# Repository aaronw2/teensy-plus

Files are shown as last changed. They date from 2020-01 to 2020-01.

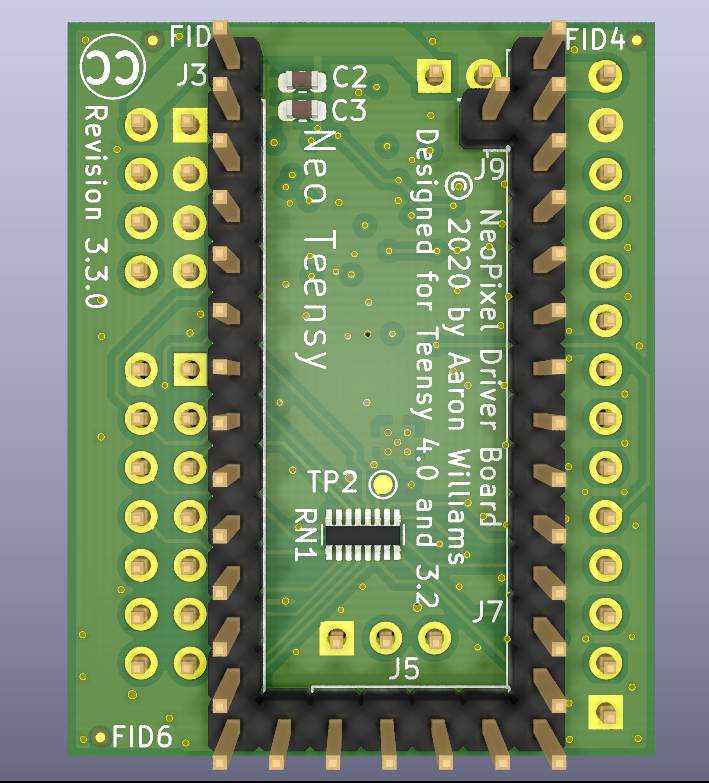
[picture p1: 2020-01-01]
Pictures/Back.png

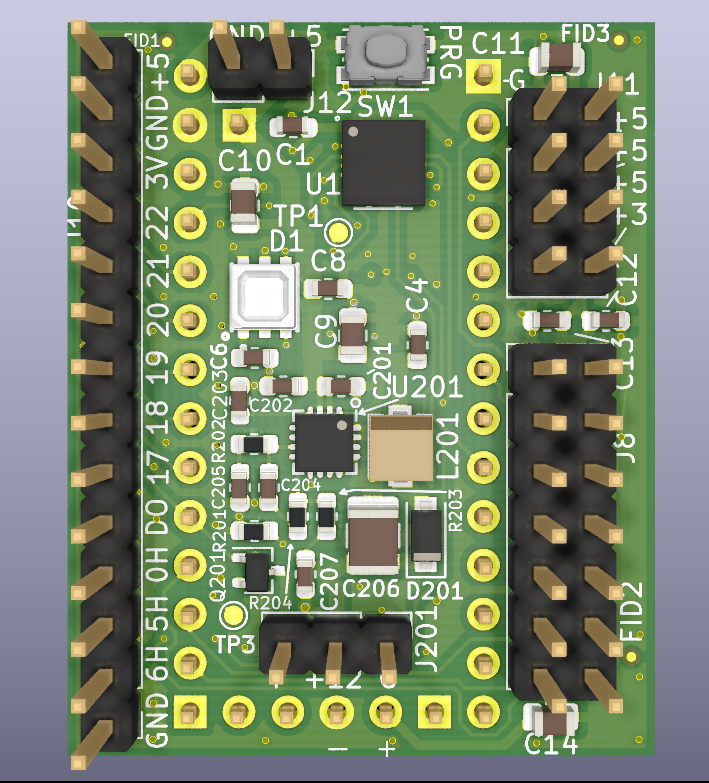
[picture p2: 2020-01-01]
Pictures/Front.png

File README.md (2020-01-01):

Teensy Plus
Revision 3.3

Copyright (C) 2019 by Aaron Williams

This board is designed to be mounted to a PJRC Teensy 4.0 and 3.2 board.
It brings out the I/Os of the Teensy and provides a 3V to 5V level shifter
and a WS2813mini NeoPixel in order to drive up to four channels of
NeoPixels.  The 5V channels should be compatible with the FastLED library
for the Teensy 4.0 (not 3.2).  In addition, this board provides a switchable
12V, 500ma output for driving a fan or other 12V accessories.  Note that
while the boost circuit is fairly efficient that it will draw around 2.75 times
as much current at 5V as the 12V output, so at 500ma it could potentially
draw around 1.4 amps.  If the 12V is not needed then it does not need to be
stuffed.

This board is designed to be mounted back-to-back with the Teensy 3.2 or
4.0 board. Note that the extra pins on the back will not be accessible
once this board is soldered in place.  It can be connected by soldering
board headers or using headers and sockets.

Not all of the pins are used and not all need to be hooked up.

On/OFF, Program and VBat are not hooked up.  Additionally J9 does not
need to be connected and can be used for an additional 5V pin.

IO0, IO1, IO2 and IO3 are passed to the level shifter and IO23 is
connected to the enable pin of the level shifter.  IO3 then goes to
the WS2813mini.

3.3V is obtained from the Teensy board which cannot supply a lot of
current.  Please do not exceed 100ma.

J8 brings provides 3.3V, ground and IO4 through IO15.  The pinout is:
J8:
1.  3.3V
2.  GND
3.  IO0
4.  IO1
5.  IO2
6.  IO3
7.  IO5
8.  IO4
9.  IO10
10. IO11
11. IO12
12. IO13
13. IO14
14. IO15

These pins are directly connected.

J10 brings out the other pins along with the 5V level shifted pins.  Note
that the level shifted pins pass through 22 ohm resistors to help reduce
noise and can optionally have capacitors connected in order to create a
low-pass filter.

Pins 2-5 pass through the level shifter, however, pin1 is an output only
that is connected to the output of the WS2813mini.

J10:
1.  GND
2.  IO8  (5V)
3.  IO9  (5V)
4.  IO6  (5V)
5.  DO   (5V, output of WS2813-mini)
6.  IO17 (3.3v, bi-directional)
7.  IO18 (3.3v, bi-directional)
8.  IO19 (3.3v, bi-directional)
9.  IO20 (3.3v, bi-directional)
10. IO21 (3.3v, bi-directional)
11. IO22 (3.3v, bi-directional)
12. 3.3V (output)
13. 5V (output)
14. Ground

J11 is used for power input and output.
1. Ground
2. +5V
3. Ground
4. +5V
5. Ground
6. +5V
7. Ground
8. +3.3V

J12 is also used for power.
1. +5V
2. Ground

J201 provides 12V at up to 500ma.
1. GND
2. +12
3. Switched ground (IO17 high enables ground), used for turning fans on/off

Power: This board can either provide 5V or receive 5V from the Teensy.
Note that it expects a battery to not be hooked up and for the input
to already be regulated to 5V.

3.3V comes from the Teensy.  Note that the Teensy can only supply a limited
amount of current at 3.3V.

Level shifter:
A SN74AHCT125N buffer is used to provide 5V I/O.  IO23 is connected
directly to the enable pin and must be pulled low in order to enable the
5V I/O. Pulling IO23 high will tri-state the bi-directional level shifter.

NOTE: Only use the Texas Instraments SN74AHCT125N!  Other manufacturers
do not support 3V input.

BOM:
C1, C2, C4, C8, C13     CAP CER 0.1UF 16V X7R 0603
C3, C65, C12            CAP CER 1UF 25V X7R 0603
C9, C10, C11, C14       CAP CER 10UF 10V X7R 0805
D1                      WS2813-MINI neopixel, available from LCSC
RN1                     47K Panasonic EXB-Q16P473J Resistor Netowrk 15
U1                      SN74AHCT125N (TI only!!!)

12V BOM:
C201                    CAP CER 22UF 16V X5R 0603
C202                    CAP CER 0.1UF 16V X7R 0603
C203                    CAP CER 0.022UF 50V X7R 0603
C204                    CAP CER 820PF 50V X7R 0603
C205                    CAP CER 0.047UF 50V X7R 0603
C206                    CAP CER 47UF 16V X5R 1210
D201                    SS24FL DIODE SCHOTTKY 40V 2A SOD123F
Q201                    BSS214NW MOSFET N-CH 20V 1.5A SOT323
R201                    RES SMD 18.7K OHM 1% 1/10W 0603
R202                    RES SMD 1.62K OHM 1% 1/10W 0603
R203                    RES SMD 86.6K OHM 1% 1/10W 0603
R204                    RES SMD 10K OHM 1% 1/10W 0603
R205                    RES SMD 100K OHM 1% 1/10W 0603
                        (can use 86.6K or higher resistor)

All components except the WS2813-mini can be sourced from Digikey.
Why did I use a WS2813-mini? I bought a reel of 1500 of them and the
footprint I have is a bit smaller than the WS2812-mini.

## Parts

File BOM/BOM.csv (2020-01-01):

Refs | Value | Footprint | Quantity | DESC | MFR | MPN | SPR | SPN | SPURL
L201 | 3.3uH | Aaron:L_Vishay_IHLP-1212 | 1 | FIXED IND 3.3UH 2.7A 61 MOHM SMD | Vishay Dale | IHLP1212BZER3R3M11 | Digikey | 541-2567-1-ND | https://www.digikey.com/product-detail/en/IHLP1212BZER3R3M11/541-2567-1-ND
U201 | TPS55340-Q1 | Aaron:QFN-16-1EP_3x3mm_P0.5mm_EP2.7x2.7mm_ThermalVias | 1 | IC REG BOOST ADJ 5.25A 16WQFN | TI | TPS55340RTER | Digikey | 296-37677-1-ND | https://www.digikey.com/products/en?keywords=296-37677-1-ND
SW1 | SW_SPST_KMR2 | Aaron:SW_SPST_KMR2 | 1 | SWITCH TACTILE SPST-NO 0.05A 32V | C&K | KMR211NG LFS | Digikey | CKN10243CT-ND | https://www.digikey.com/product-detail/en/c-k/KMR211NG-LFS/CKN10243CT-ND/2176494
C2;C13;C8;C4;C1;C202 | 0.1uF | Capacitor_SMD:C_0603_1608Metric | 6 | CAP CER 0.1UF 16V X7R 0603 | Samsung | CL10B104KO8WPNC | Digikey | 1276-6582-1-ND | https://www.digikey.com/products/en?keywords=1276-6582-1-ND
C3;C12;C6;C207 | 1uF | Capacitor_SMD:C_0603_1608Metric | 4 | CAP CER 1UF 25V X7R 0603 | Samsung | CL10B105KA8NNNC | Digikey | 1276-1184-1-ND | https://www.digikey.com/products/en?keywords=1276-1184-1-ND
C203 | 22nF | Capacitor_SMD:C_0603_1608Metric | 1 | CAP CER 0.022UF 50V X7R 0603 | Samsung | CL10B223KB8WPNC | Digikey | 1276-6534-1-ND | https://www.digikey.com/products/en?keywords=1276-6534-1-ND
C201 | 22uF | Capacitor_SMD:C_0603_1608Metric | 1 | CAP CER 22UF 16V X5R 0603 | Samsung Electro-Mechanics | CL10A226MO7JZNC | Digikey | 1276-7076-1-ND | https://www.digikey.com/products/en?keywords=1276-7076-1-ND
C205 | 47nF | Capacitor_SMD:C_0603_1608Metric | 1 | CAP CER 0.047UF 50V X7R 0603 | Samsung Electro-Mechanics | CL10B473KB8WPNC | Digikey | 1276-6540-1-ND | https://www.digikey.com/product-detail/en/samsung-electro-mechanics/CL10B473KB8WPNC/1276-6540-1-ND/
C204 | 820pF | Capacitor_SMD:C_0603_1608Metric | 1 | CAP CER 820PF 50V X7R 0603 | Kemet | C0603C821J5RACTU | Digikey | 399-9127-1-ND | https://www.digikey.com/products/en?keywords=399-9127-1-ND
C14;C9;C11;C10 | 10uF | Capacitor_SMD:C_0805_2012Metric | 4 | CAP CER 10UF 10V X7R 0805 | Murata Electronics | GRM21BR71A106KA73K | Digikey | 490-14381-1-ND | https://www.digikey.com/products/en?keywords=490-14381-1-ND
C206 | 47uF | Capacitor_SMD:C_1210_3225Metric | 1 | CAP CER 47UF 16V X5R 1210 | Samsung | CL32A476KOJNNNE | Digikey | 1276-3376-1-ND | https://www.digikey.com/product-detail/en/samsung-electro-mechanics/CL32A476KOJNNNE/1276-3376-1-ND/3891462
J9 | Conn_01x01_Male | Connector_PinHeader_2.54mm:PinHeader_1x01_P2.54mm_Vertical | 1 | - | - | - | - | - | -
J12 | Conn_01x02 | Connector_PinHeader_2.54mm:PinHeader_1x02_P2.54mm_Vertical | 1 | - | - | - | - | - | -
J201 | Conn_01x03 | Connector_PinHeader_2.54mm:PinHeader_1x03_P2.54mm_Vertical | 1 | - | - | - | - | - | -
J5 | Conn_01x05_Male | Connector_PinHeader_2.54mm:PinHeader_1x05_P2.54mm_Vertical | 1 | - | - | - | - | - | -
J10 | Conn_01x14 | Connector_PinHeader_2.54mm:PinHeader_1x14_P2.54mm_Vertical | 1 | - | - | - | - | - | -
J3;J7 | Conn_01x14_Male | Connector_PinHeader_2.54mm:PinHeader_1x14_P2.54mm_Vertical | 2 | - | - | - | - | - | -
J11 | Conn_02x04_Odd_Even | Connector_PinHeader_2.54mm:PinHeader_2x04_P2.54mm_Vertical | 1 | - | - | - | - | - | -
J8 | Conn_02x07_Odd_Even | Connector_PinHeader_2.54mm:PinHeader_2x07_P2.54mm_Vertical | 1 | - | - | - | - | - | -
D201 | SS24FL | Diode_SMD:D_SOD-123F | 1 | DIODE SCHOTTKY 40V 2A SOD123F | ON | SS24FL | Digikey | SS24FLCT-ND | https://www.digikey.com/products/en?keywords=SS24FLCT-ND
D1 | WS2813-MINI | LED_WS2813-mini:LED_WS2813-MINI-2 | 1 | RGB 620~625nm Red, 515~525nm Green, 465~475nm Blue SMD-6 Light Emitting Diodes (LED) RoHS | Worldsemi | WS2813-Mini(WS2813-3535) | LCSC | C189639 | https://lcsc.com/product-detail/Others_WS2813-Mini-WS2813-3535_C189639.html
U1 | SN74AHCT125N | Package_DFN_QFN:Texas_S-PVQFN-N14 | 1 | IC BUF NON-INVERT 5.5V 14VQFN | Texas Instruments | SN74AHCT125RGYR | Digikey | 296-13910-1-ND | https://www.digikey.com/products/en?keywords=296-13910-1-ND
Q201 | BSS214NW | Package_TO_SOT_SMD:SOT-323_SC-70 | 1 | MOSFET N-CH 20V 1.5A SOT323 | Infineon | BSS214NWH6327XTSA1 | Digikey | BSS214NWH6327XTSA1CT-ND | https://www.digikey.com/products/en?keywords=BSS214NWH6327XTSA1CT-ND
R202 | 1.62k | Resistor_SMD:R_0603_1608Metric | 1 | RES SMD 1.62K OHM 1% 1/10W 0603 | Yageo | RC0603FR-071K62L | Digikey | 311-1.62KHRCT-ND | https://www.digikey.com/product-detail/en/yageo/RC0603FR-071K62L/311-1.62KHRCT-ND/729816
R204 | 10k | Resistor_SMD:R_0603_1608Metric | 1 | RES SMD 10K OHM 1% 1/10W 0603 | Vishay Dale | CRCW060310K0FKEC | Digikey | 541-2979-1-ND | https://www.digikey.com/products/en?keywords=541-2979-1-ND
R201 | 18.7K | Resistor_SMD:R_0603_1608Metric | 1 | RES SMD 18.7K OHM 1% 1/10W 0603 | Yageo | RC0603FR-0718K7L | Digikey | 311-18.7KHRCT-ND | https://www.digikey.com/product-detail/en/yageo/RC0603FR-0718K7L/311-18.7KHRCT-ND/729940
R203 | 86.6k | Resistor_SMD:R_0603_1608Metric | 1 | RES SMD 86.6K OHM 1% 1/10W 0603 | Vishay Dale | CRCW060386K6FKEA | Digikey | 541-86.6KHCT-ND | https://www.digikey.com/products/en?keywords=541-86.6KHCT-ND
RN1 | 47K | Resistor_SMD:R_Array_Convex_8x0602 | 1 | RES ARRAY 15 RES 47K OHM 1506 | Panasonic | EXB-Q16P473J | Digikey | U6473CT-ND | https://www.digikey.com/product-detail/en/panasonic-electronic-components/EXB-Q16P473J/U6473CT-ND/672854

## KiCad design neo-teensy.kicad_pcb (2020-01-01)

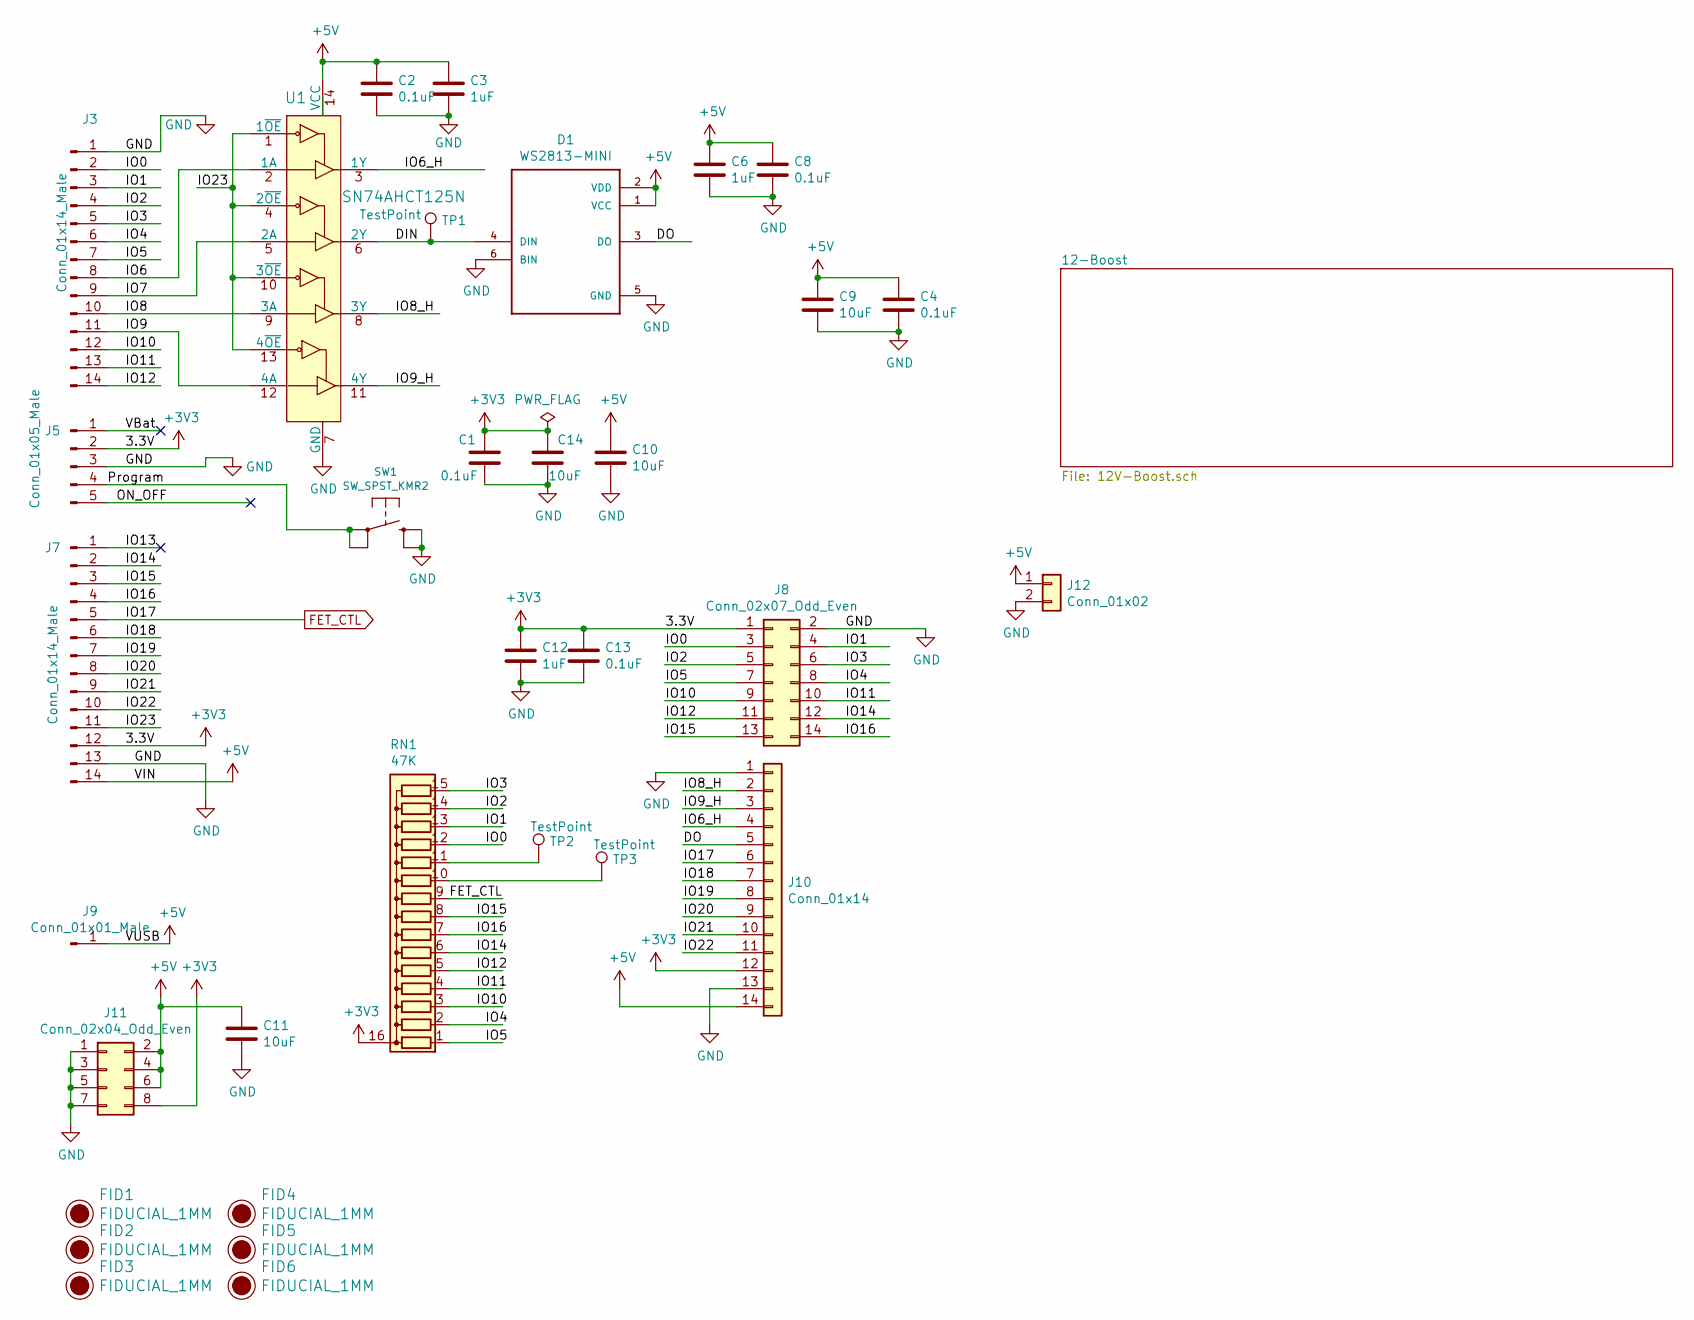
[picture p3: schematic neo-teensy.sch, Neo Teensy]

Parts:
C1, C2, C4, C8, C13: 0.1uF; C_0603_1608Metric; MPN CL10B104KO8WPNC
C3, C6, C12: 1uF; C_0603_1608Metric; MPN CL10B105KA8NNNC
C9, C10, C11, C14: 10uF; C_0805_2012Metric; MPN GRM21BR71A106KA73K
D1: WS2813-MINI; LED_WS2813-MINI-2; MPN WS2813-Mini(WS2813-3535)
FID1, FID2, FID3, FID4, FID5, FID6: FIDUCIAL_1MM; Fiducial_0.5mm_Mask1mm
J3, J7: Conn_01x14_Male; PinHeader_1x14_P2.54mm_Vertical
J5: Conn_01x05_Male; PinHeader_1x05_P2.54mm_Vertical
J8: Conn_02x07_Odd_Even; PinHeader_2x07_P2.54mm_Vertical
J9: Conn_01x01_Male; PinHeader_1x01_P2.54mm_Vertical
J10: Conn_01x14; PinHeader_1x14_P2.54mm_Vertical
J11: Conn_02x04_Odd_Even; PinHeader_2x04_P2.54mm_Vertical
J12: Conn_01x02; PinHeader_1x02_P2.54mm_Vertical
RN1: 47K; R_Array_Convex_8x0602; MPN EXB-Q16P473J
SW1: SW_SPST_KMR2; MPN KMR211NG LFS
TP1, TP2, TP3: TestPoint; TestPoint_Pad_D1.0mm
U1: SN74AHCT125N; Texas_S-PVQFN-N14; MPN SN74AHCT125RGYR; Digi-Key_PN 296-4655-5-ND

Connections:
+3V3: C1.1, C12.1, C13.1, C14.1, J5.2, J7.12, J8.1, J10.12, J11.8, RN1.16 (common)
+5V: C2.1, C3.1, C4.1, C6.1, C8.1, C9.1, C10.1, C11.1, D1.1 (VCC), D1.2 (VDD), J7.14, J9.1, J10.14, J11.2, J11.4, J11.6, J12.1, U1.14 (VCC); also elsewhere on the board
/DIN: D1.4 (DIN), TP1.1, U1.6 (2Y)
/DO: D1.3 (DO), J10.5
/IO0: J3.2, J8.3, RN1.12 (R11)
/IO1: J3.3, J8.4, RN1.13 (R12)
/IO2: J3.4, J8.5, RN1.14 (R13)
/IO3: J3.5, J8.6, RN1.15
/IO4: J3.6, J8.8, RN1.2 (R1)
/IO5: J3.7, J8.7, RN1.1
/IO6: J3.8, U1.2 (1A)
/IO6_H: J10.4, U1.3 (1Y)
/IO7: J3.9, U1.5 (2A)
/IO8: J3.10, U1.9 (3A)
/IO8_H: J10.2, U1.8 (3Y)
/IO9: J3.11, U1.12 (4A)
/IO9_H: J10.3, U1.11 (4Y)
/IO10: J3.12, J8.9, RN1.3 (R2)
/IO11: J3.13, J8.10, RN1.4 (R3)
/IO12: J3.14, J8.11, RN1.5 (R4)
/IO13: J7.1
/IO14: J7.2, J8.12, RN1.6 (R5)
/IO15: J7.3, J8.13, RN1.8 (R7)
/IO16: J7.4, J8.14, RN1.7 (R6)
/IO18: J7.6, J10.7
/IO19: J7.7, J10.8
/IO20: J7.8, J10.9
/IO21: J7.9, J10.10
/IO22: J7.10, J10.11
/IO23: J7.11, U1.1 (1~OE), U1.4 (2~OE), U1.10 (3~OE), U1.13 (4~OE)
/ON_OFF: J5.5
/Program: J5.4, SW1.1
/VBat: J5.1
FET_CTL: J7.5, J10.6, RN1.9 (R8); also elsewhere on the board
GND: C1.2, C2.2, C3.2, C4.2, C6.2, C8.2, C9.2, C10.2, C11.2, C12.2, C13.2, C14.2, D1.5 (GND), D1.6 (BIN), J3.1, J5.3, J7.13, J8.2, J10.1, J10.13, J11.1, J11.3, J11.5, J11.7, J12.2, SW1.2 (S), U1.7 (GND); also elsewhere on the board
unnamed: RN1.10 (R9), TP3.1
unnamed: RN1.11 (R10), TP2.1

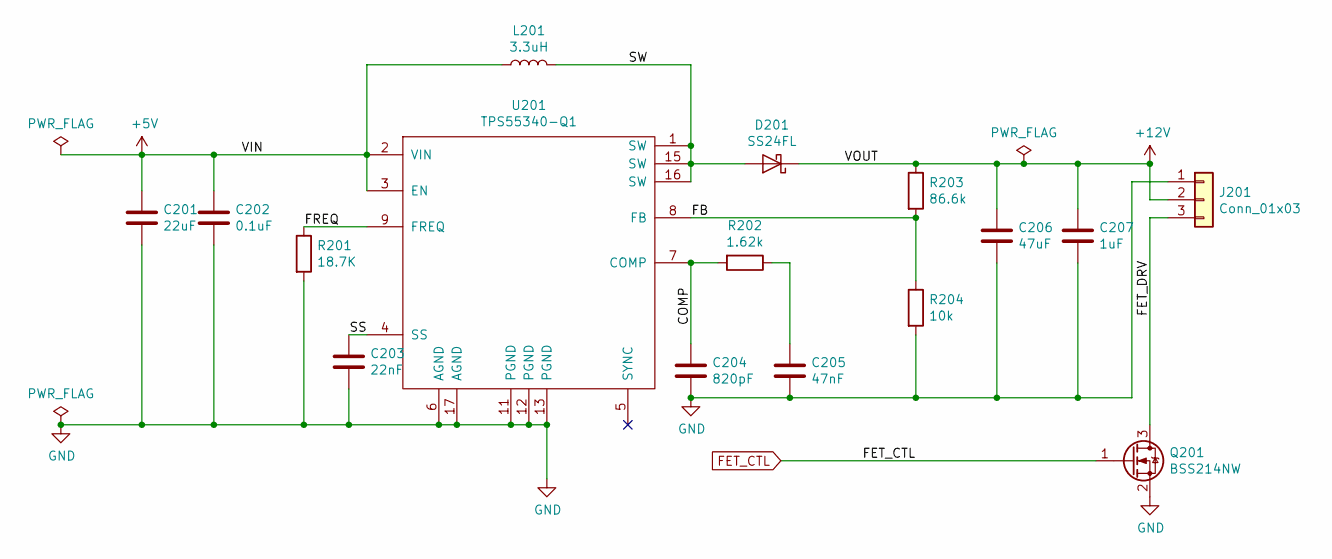
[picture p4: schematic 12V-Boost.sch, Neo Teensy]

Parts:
C201: 22uF; C_0603_1608Metric; MPN CL10A226MO7JZNC
C202: 0.1uF; C_0603_1608Metric; MPN CL10B104KO8WPNC
C203: 22nF; C_0603_1608Metric; MPN CL10B223KB8WPNC
C204: 820pF; C_0603_1608Metric; MPN C0603C821J5RACTU
C205: 47nF; C_0603_1608Metric; MPN CL10B473KB8WPNC
C206: 47uF; C_1210_3225Metric; MPN CL32A476KOJNNNE
C207: 1uF; C_0603_1608Metric; MPN CL10B105KA8NNNC
D201: SS24FL; D_SOD-123F; MPN SS24FL
J201: Conn_01x03; PinHeader_1x03_P2.54mm_Vertical
L201: 3.3uH; L_Vishay_IHLP-1212; MPN IHLP1212BZER3R3M11
Q201: BSS214NW; SOT-323_SC-70; MPN BSS214NWH6327XTSA1
R201: 18.7K; R_0603_1608Metric; MPN RC0603FR-0718K7L
R202: 1.62k; R_0603_1608Metric; MPN RC0603FR-071K62L
R203: 86.6k; R_0603_1608Metric; MPN CRCW060386K6FKEA
R204: 10k; R_0603_1608Metric; MPN CRCW060310K0FKEC
U201: TPS55340-Q1; QFN-16-1EP_3x3mm_P0.5mm_EP2.7x2.7mm_ThermalVias; MPN TPS55340RTER

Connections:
+5V: C201.1, C202.1, L201.1, U201.2 (VIN), U201.3 (EN); also elsewhere on the board
+12V: C206.1, C207.1, D201.1 (K), J201.2, R203.1
/12-Boost/COMP: C204.1, R202.2, U201.7 (COMP)
/12-Boost/FB: R203.2, R204.1, U201.8 (FB)
/12-Boost/FET_DRV: J201.3, Q201.3 (D)
/12-Boost/FREQ: R201.1, U201.9 (FREQ)
/12-Boost/SS: C203.1, U201.4 (SS)
/12-Boost/SW: D201.2 (A), L201.2, U201.1 (SW), U201.15 (SW), U201.16 (SW)
FET_CTL: Q201.1 (G); also elsewhere on the board
GND: C201.2, C202.2, C203.2, C204.2, C205.2, C206.2, C207.2, J201.1, Q201.2 (S), R201.2, R204.2, U201.6 (AGND), U201.11 (PGND), U201.12 (PGND), U201.13 (PGND), U201.17 (AGND); also elsewhere on the board
unnamed: C205.1, R202.1

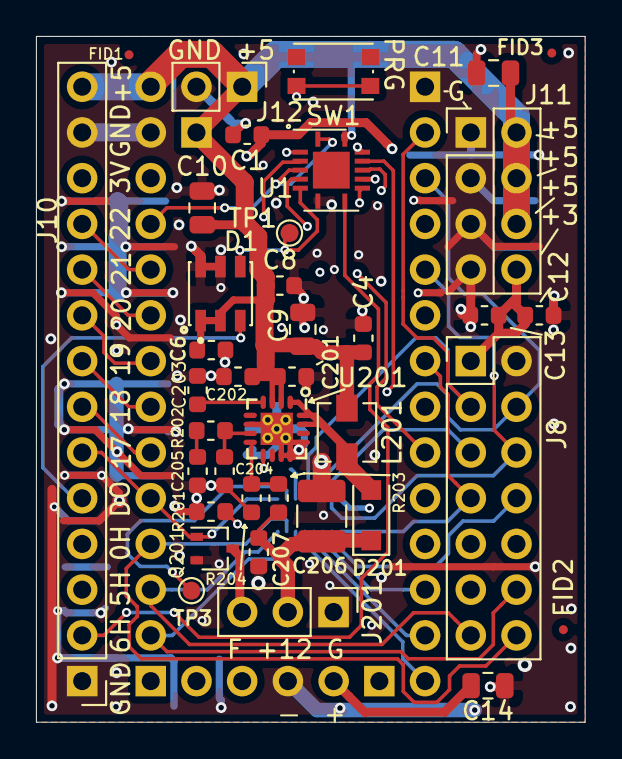
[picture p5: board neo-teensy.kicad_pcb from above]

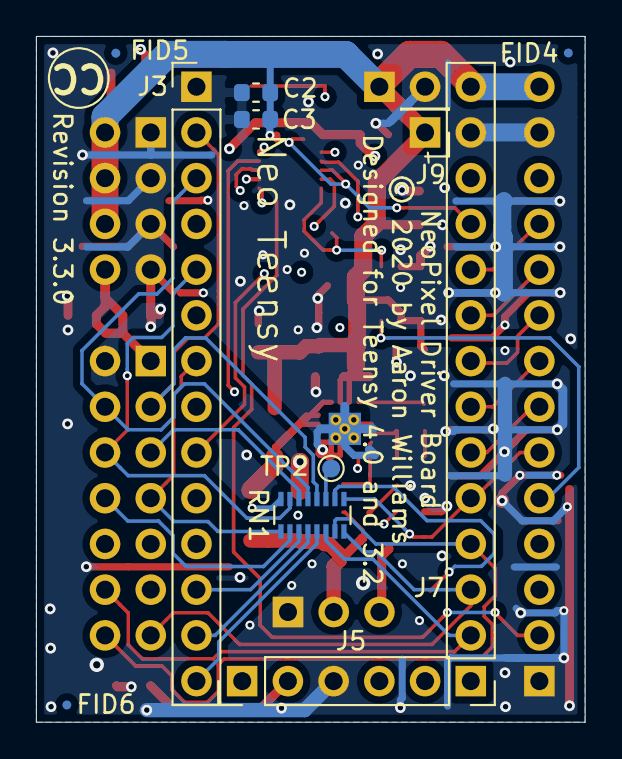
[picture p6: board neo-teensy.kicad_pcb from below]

Board: 4 copper layers, 30.5 x 38.1 mm, 49 parts (11 on the bottom side), 42 nets.

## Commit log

2019-11-11 Initial commit of revision 1.1.
    [teensy-plus.kicad_pcb, teensy-plus.sch]
2019-11-17 Changed 5V I/O pins to be compatible with FastLED
    Also updated the README and added a BOM and other minor cleanups.
    [BOM.csv, teensy-plus.kicad_pcb, teensy-plus.sch]
2019-11-20 Committed version 2.0
    - Board is smaller
    - Now designed to be mounted to the bottom of a Teensy
    - Added connector to solder on 12V supply.
    [teensy-plus-2.kicad_pcb, teensy-plus-2.sch, teensy-plus.kicad_pcb]
2019-11-21 Updated to version 3.0
    - Changed to 74AHCT125
    - Removed 22 ohm resistors
    - IO23 is now active low
    [teensy-plus-2.kicad_pcb, teensy-plus-2.sch]
2019-11-21 Minor silk screen change. Retag 3.0.0
    [teensy-plus-2.kicad_pcb]
2019-11-21 Renamed project neo-teensy
    Rev 3.0
    [neo-teensy.kicad_pcb, neo-teensy.sch]
2019-11-21 Minor silk-screen fix.
    [neo-teensy.kicad_pcb]
2019-11-21 Minor cleanup.
    [neo-teensy.kicad_pcb, neo-teensy.sch]
2019-11-22 Updated BOM
    [BOM.csv, neo-teensy.sch]
2019-11-25 Removed connectors and added 12V boost
    Version 3.1.0
    [12V-Boost.sch, neo-teensy.kicad_pcb, neo-teensy.sch]
2019-12-01 Fixed GPIO 13, GPIO 16 and GPIO 17 for the fan control.
    [12V-Boost.sch, neo-teensy.kicad_pcb, neo-teensy.sch]
2019-12-01 Minor fixups, changed solder mask.
    [neo-teensy.kicad_pcb]
2019-12-30 Changed GPIOs for Teensy 4.0
    The 5V GPIOs were changed for the Teensy 4.0. In addition the GPIOs to
    the 14 pin header were also changed.
    Some component values were also changed for the power supply.
    Note that this is still compatible with the 3.1 stencil.
    This also fixes the 12V BOM.
    [12V-Boost.sch, BOM.csv, neo-teensy.kicad_pcb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]
2020-01-01 Added pull-up resistors to 14-pin header
    Made board 4 layers
    Made board double sided
    [12V-Boost.sch, BOM.csv, neo-teensy.kicad_pcb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]

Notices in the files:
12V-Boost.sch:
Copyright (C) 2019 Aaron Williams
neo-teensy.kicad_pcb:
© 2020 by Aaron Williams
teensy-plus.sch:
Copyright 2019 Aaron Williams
